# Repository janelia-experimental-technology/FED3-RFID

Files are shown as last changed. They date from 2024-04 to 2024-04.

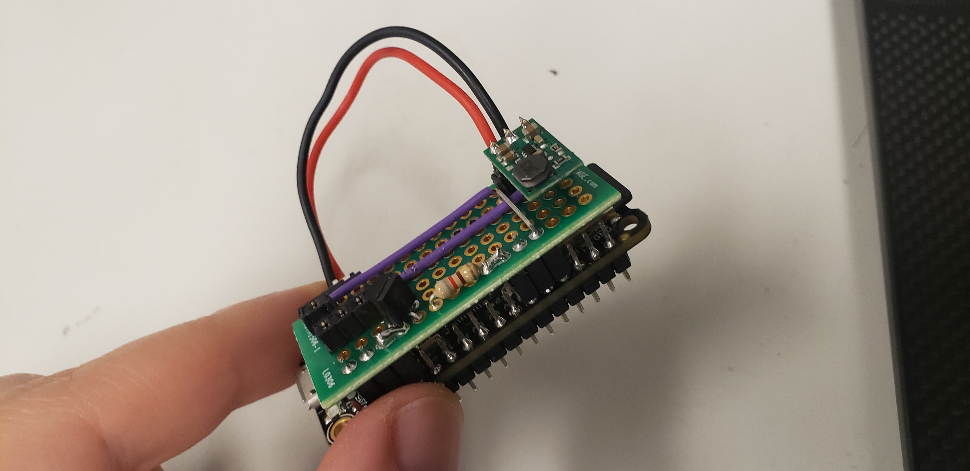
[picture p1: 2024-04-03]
ELECTRONICS/PHOTOS/20240327_181440.jpg

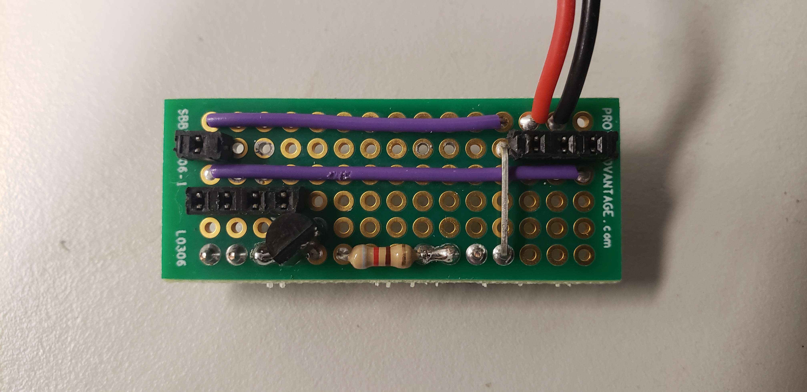
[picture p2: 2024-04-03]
ELECTRONICS/PHOTOS/20240327_181220.jpg

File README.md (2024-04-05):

This repo contains all the files necessary to integrate RFID with the Feeding Experimentation Device version 3 (FED3), originally developed by KravitzLabDevices.
This reader is compatible with FDX-B 134.2 kHz ISO 11784/85 transponders; the firmware was specifically developed to log both ID and temperature using the Biothem 13 Pit tags: https://www.biomark.com/product/biotherm13-pit-tag/

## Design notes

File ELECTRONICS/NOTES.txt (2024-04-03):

Refer to schematic, photos, and parts list for build.
In order to fit all electronics within the housing, short headers (male and female) should be used to limit height.
A 2mm JST connector can be used to connect the boost converter to the battery output from the Adafruit Feather M0.
A 2N4401 NPN BJT transistor was used, but a 2N2222 or similar would work just as well; be sure to adjust resistor value as needed.
It is advised to disconnect the battery from the FED3 board when not in use, ~18mA is drawn from the battery even when the FED3 is powered down.

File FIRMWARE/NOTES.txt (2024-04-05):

Upload "ClassicFED3_RFID.ino" in the examples folder to the Adafruit Feather M0 Adalogger.
The .cpp and .h files in "src" folder have been modified from the original FED3 code to allow for RFID integration.
Please note that RFID logging is currently only available on FEDModes 0-3.

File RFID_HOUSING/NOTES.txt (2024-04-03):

Files are for the acrylic antenna and tube mount which will attach to the FED3 housing - intended to be laser cut. 
Coil approximately 75 revolutions of 36 AWG magnet wire around tube to achieve an inductance of ~580uH.
Feed antenna wire through right nose-poke port to RFID reader board.
Make sure the antenna coil will be in close proximity to the animal's RFID tag.
Use three 2-56 screws and tap base plate to secure all acrylic sections together.
Press-fit two 6-32 nuts into base plate (make sure they are attracted to magnetic buttons on FED3).

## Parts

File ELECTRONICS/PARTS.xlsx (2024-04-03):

FED3 Documentation: | Ref Des | Link
Research |  | https://elifesciences.org/articles/66173
GitHub |  | https://github.com/KravitzLabDevices/FED3
Hardware:
Adafruit Feather Adalogger M0 | U3 | https://learn.adafruit.com/adafruit-feather-m0-adalogger/pinouts
9V Boost Converter | U2 | https://www.pololu.com/product/4944
FDX-B RFID Reader | U1 | https://www.amazon.com/LICHIFIT-134-2K-Module-ISO11784-Distance/dp/B0B8NXKPZB
Perf Board |  | https://www.digikey.com/en/products/detail/chip-quik-inc/SBBTH1506-1/5978222
Battery |  | https://www.pknergy.com/lithium-ion-battery-pack-3-7v-4400mah-2-product/?_gl=1*16tqxgu*_up*MQ..
820Ω resistor | R1
2N4401 BJT | Q1
24 AWG solid core wire
2mm JST connector (2 pos)
Female Headers |  | https://www.digikey.com/en/products/detail/3m/929870-01-10-RA/1239313?gad_source=1

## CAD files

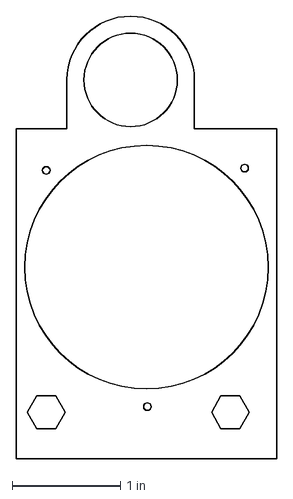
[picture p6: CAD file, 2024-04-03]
RFID_HOUSING/LASER CUT/BASE_PLATE.dxf
2.41 x 4.09 in

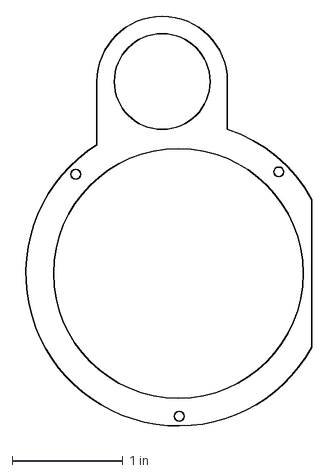
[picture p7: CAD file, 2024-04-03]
RFID_HOUSING/LASER CUT/TUBE_RING.dxf
2.67 x 3.76 in

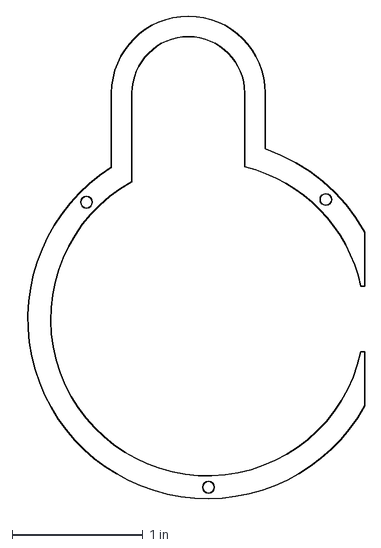
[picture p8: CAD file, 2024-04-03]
RFID_HOUSING/LASER CUT/ANTENNA_RING.dxf
2.67 x 3.76 in

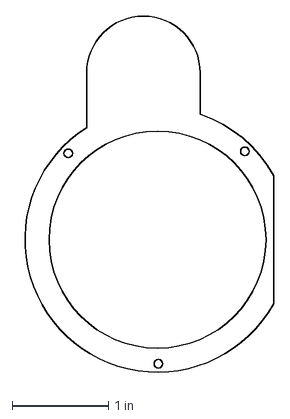
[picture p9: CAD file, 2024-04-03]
RFID_HOUSING/LASER CUT/END_CAP.dxf
2.67 x 3.76 in

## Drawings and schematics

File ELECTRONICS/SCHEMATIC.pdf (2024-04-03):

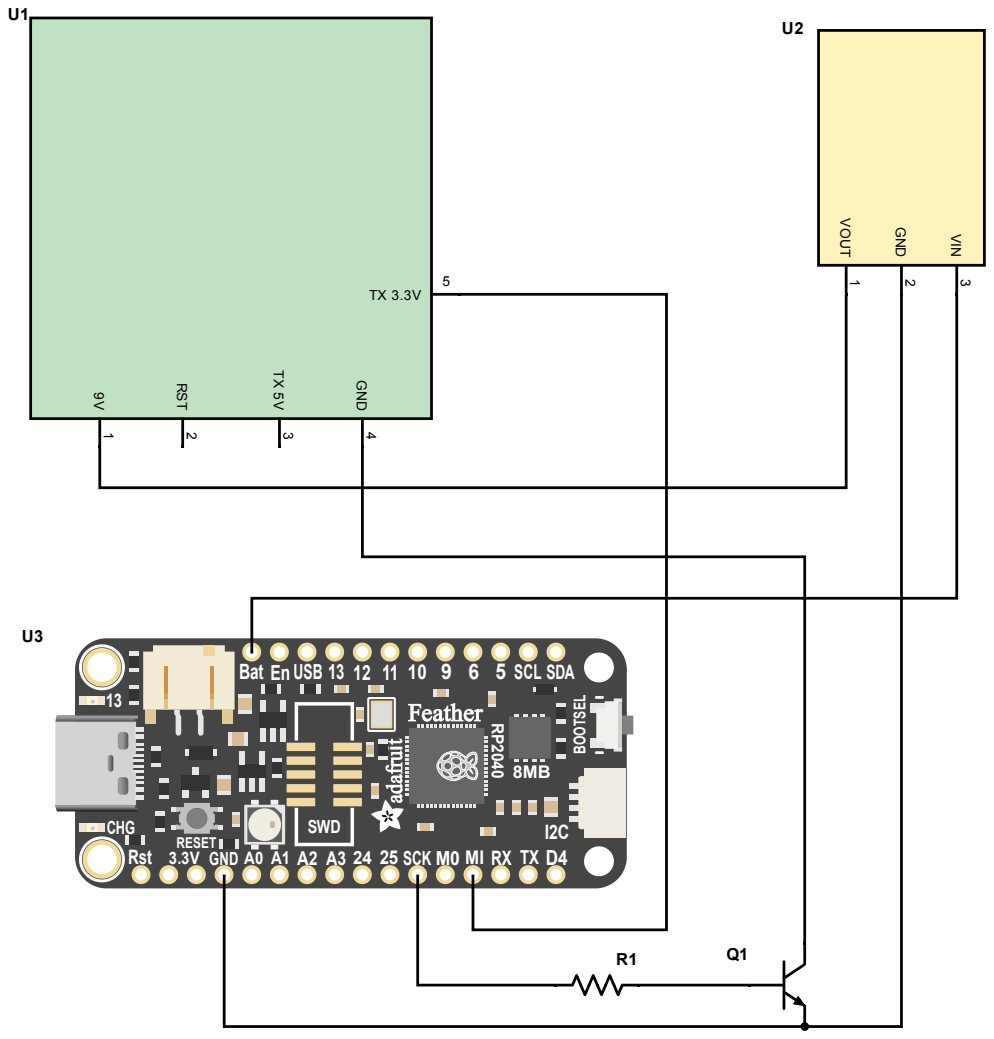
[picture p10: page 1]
RST; GND; V OUT; VIN; OTSEL; Feather; afruit; I2C RESET; CHG; SWD

Bat En USB 13 12 11 10 9

Rst 3.3V GND A0 A1 A2 A3 24 25 SCK M0 MI RX TX D4

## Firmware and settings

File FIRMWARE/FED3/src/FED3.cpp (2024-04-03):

/*
  RFID capabilities have been integrated into this program
  RFID reader: https://www.amazon.com/LICHIFIT-134-2K-Module-ISO11784-Distance/dp/B0B8NXKPZB
  Transponders: https://www.biomark.com/product/biotherm13-pit-tag/

  Daniel K. Smith
  smithd3@janelia.hhmi.org
  March 1, 2024

  /////////////////////////////////////////////////////////////////////////////////////////////////

  Feeding experimentation device 3 (FED3) library
  Code by Lex Kravitz, adapted to Arduino library format by Eric Lin
  alexxai@wustl.edu
  erclin@ucdavis.edu
  December 2020 

  The first FED device was developed by Nguyen at al and published in 2016:
  https://www.ncbi.nlm.nih.gov/pubmed/27060385

  FED3 includes hardware and code from:
  *** Adafruit, who made the hardware breakout boards and associated code we used in FED ***

  Cavemoa's excellent examples of datalogging with the Adalogger:
  https://github.com/cavemoa/Feather-M0-Adalogger

  Arduino Time library http://playground.arduino.cc/code/time
  Maintained by Paul Stoffregen https://github.com/PaulStoffregen/Time

  This project is released under the terms of the Creative Commons - Attribution - ShareAlike 3.0 license:
  human readable: https://creativecommons.org/licenses/by-sa/3.0/
  legal wording: https://creativecommons.org/licenses/by-sa/3.0/legalcode
  Copyright (c) 2019, 2020 Lex Kravitz
*/


/**************************************************************************************************************************************************
                                                                                                    Startup stuff
**************************************************************************************************************************************************/
#include "Arduino.h"
#include "FED3.h"

//  Start FED3 and RTC objects
FED3 *pointerToFED3;
RTC_PCF8523 rtc; 

//  Interrupt handlers
static void outsidePelletTriggerHandler(void) {
  pointerToFED3->pelletTrigger();
}

static void outsideLeftTriggerHandler(void) {
  pointerToFED3->leftTrigger();
}

static void outsideRightTriggerHandler(void) {
  pointerToFED3->rightTrigger();
}

/**************************************************************************************************************************************************
                                                                                                        Main loop
**************************************************************************************************************************************************/
void FED3::run() {
  //This should be called at least once per loop.  It updates the time, updates display, and controls sleep 
  if (digitalRead(PELLET_WELL) == HIGH) {  //check for pellet
    PelletAvailable = false;
  }
  DateTime now = rtc.now();
  currentHour = now.hour(); //useful for timed feeding sessions
  currentMinute = now.minute(); //useful for timed feeding sessions
  currentSecond = now.second(); //useful for timed feeding sessions
  unixtime = now.unixtime();
  ReadBatteryLevel();
  UpdateDisplay();
  goToSleep();
}

/**************************************************************************************************************************************************
                                                                                                Poke functions
**************************************************************************************************************************************************/
//log left poke
void FED3::logLeftPoke(){
  if (PelletAvailable == false){
    leftPokeTime = millis();
    LeftCount ++;
    leftInterval = 0.0;
    while (digitalRead (LEFT_POKE) == LOW) {}  //Hang here until poke is clear
    leftInterval = (millis()-leftPokeTime);
    UpdateDisplay();
    DisplayLeftInt();
    if (leftInterval < minPokeTime) {
      Event = "LeftShort";
    }
    else{
      Event = "Left";
    }
    logdata();
    Left = false;
  }
}

//log right poke
void FED3::logRightPoke(){
  if (PelletAvailable == false){
    rightPokeTime = millis();
    RightCount ++;
    rightInterval = 0.0;
    while (digitalRead (RIGHT_POKE) == LOW) {} //Hang here until poke is clear
    rightInterval = (millis()-rightPokeTime);
    UpdateDisplay();
    DisplayRightInt();
    if (rightInterval < minPokeTime) {
      Event = "RightShort";
    }
    else{
      Event = "Right";
    }
    logdata();
    Right = false; 
  }
}

void FED3::randomizeActivePoke(int max){
  //Store last active side and randomize
  byte lastActive = activePoke;
  activePoke = random (0, 2);

  //Increment consecutive active pokes, or reset consecutive to zero
  if (activePoke == lastActive) {
    consecutive ++;
  }
  else {
    consecutive = 0;
  }
  
  //if consecutive pokes are too many, swap pokes
  if (consecutive >= max){
    if (activePoke == 0) {
      activePoke = 1;
    }
    else if (activePoke == 1) {
      activePoke = 0;
    }
    consecutive = 0;
    }
}
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

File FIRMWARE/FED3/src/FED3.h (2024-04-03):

/*
RFID capabilities have been integrated into this program
RFID reader: https://www.amazon.com/LICHIFIT-134-2K-Module-ISO11784-Distance/dp/B0B8NXKPZB
Transponders: https://www.biomark.com/product/biotherm13-pit-tag/

Daniel K. Smith
smithd3@janelia.hhmi.org
March 1, 2024

/////////////////////////////////////////////////////////////////////////////////////////////////

Feeding experimentation device 3 (FED3) library 
Code by Lex Kravitz, adapted to Arduino library format by Eric Lin
alexxai@wustl.edu
May 2021

The original FED device was developed by Katrina Nguyen at al in 2016:
https://www.ncbi.nlm.nih.gov/pubmed/27060385

This device includes hardware and code from:
  *** Adafruit, who made the hardware breakout boards and associated code we used in FED ***

  Cavemoa's excellent examples of datalogging with the Adalogger:
  https://github.com/cavemoa/Feather-M0-Adalogger

  Arduino Time library http://playground.arduino.cc/code/time
  Maintained by Paul Stoffregen https://github.com/PaulStoffregen/Time

  This project is released under the terms of the Creative Commons - Attribution - ShareAlike 3.0 license:
  human readable: https://creativecommons.org/licenses/by-sa/3.0/
  legal wording: https://creativecommons.org/licenses/by-sa/3.0/legalcode
  Copyright (c) 2019, 2020 Lex Kravitz
*/

#define VER "1.16.3"

#ifndef FED3_H
#define FED3_H

//include these libraries
#include <Arduino.h>
#include <Adafruit_BusIO_Register.h>
#include <Adafruit_I2CDevice.h>
#include <Adafruit_I2CRegister.h>
#include <Adafruit_SPIDevice.h>
#include <Wire.h>
#include <SPI.h>
#include <Stepper.h>
#include <ArduinoLowPower.h>
#include "RTClib.h"
#include <SdFat.h>
#include <Adafruit_GFX.h>
#include <Adafruit_SharpMem.h>
#include <Fonts/FreeSans9pt7b.h>
#include <Fonts/Org_01.h>
#include <Adafruit_NeoPixel.h>
#include <Adafruit_AHTX0.h>

// Pin definitions
#define NEOPIXEL        A1
#define MOTOR_ENABLE    13
#define GREEN_LED       8
#define PELLET_WELL     1
#define LEFT_POKE       6
#define RIGHT_POKE      5            //DISABLE RIGHT NOSE-POKE (OTHERWISE PIN 5)
#define BUZZER          0
#define VBATPIN         A7
#define cardSelect      4
#define BNC_OUT         A0
#define SHARP_SCK       12
#define SHARP_MOSI      11
#define SHARP_SS        10
#define RFID_RST        24
         

#define BLACK 0
#define WHITE 1
#define STEPS 2038

extern bool Left;

class FED3 {
    // Members
    public:
        FED3(String sketch);
        String sketch = "undef";
        String sessiontype = "undef";

        void classInterruptHandler(void);
        void begin();
        void run();
        
        // SD logging
        SdFat SD;
        File logfile;       // Create file object
        File ratiofile;     // Create another file object
        File configfile;    // Create another file object
        File startfile;     // Create another file object
        File stopfile;      // Create another file object
        char filename[21];  // Array for file name data logged to named in setup
        void logdata();
        void CreateFile();
        void CreateDataFile ();
        void writeHeader();
        void writeConfigFile();
        void writeFEDmode();
        void error(uint8_t errno);
        void getFilename(char *filename);
        bool suppressSDerrors = false;  //set to true to suppress SD card errors at startup 

        // Battery
        float measuredvbat = 1.0;
        void ReadBatteryLevel();

        // Neopixel
        void pixelsOn(int R, int G, int B, int W);
        void pixelsOff();
        void Blink(byte PIN, byte DELAY_MS, byte loops);
        void colorWipe(uint32_t c, uint8_t wait);
        void leftPixel(int R, int G, int B, int W);
        void rightPixel(int R, int G, int B, int W);
        void leftPokePixel(int R, int G, int B, int W);
        void rightPokePixel(int R, int G, int B, int W);
        
        // Display functions
        void UpdateDisplay();
        void DisplaySDError();
        void DisplayJamClear();
        void DisplayRetrievalInt();
        void DisplayLeftInt();
        void DisplayRightInt();
        void DisplayBattery();
        void DisplayDateTime();
        void DisplayIndicators();
        void DisplayTimedFeeding();
        void DisplayNoProgram();
        void DisplayMinPoke();
        void DisplayMouse();

        // Startup menu function
        void ClassicMenu();
        void StartScreen();
        void FED3MenuScreen();
        void SetClock();
        
        //BNC input/output
		void ReadBNC(bool blinkGreen);
        bool BNCinput = false;
        
        // Motor
        void ReleaseMotor();
        int numMotorTurns = 0;

        // Set FED
        void SelectMode();
        void SetDeviceNumber();

        // Stimuli
        void ConditionedStimulus(int duration = 200);
        void Click();
        void Noise(int duration = 200);
        void BNC(int DELAY_MS, int loops);
        void pulseGenerator(int pulse_width, int frequency, int repetitions);

        void Tone(int freq, int duration);
        void stopTone();
        
        // Pelet and poke functions
        void CheckRatio();
        void logLeftPoke();
        void logRightPoke();
        void Feed(int pulse = 0, bool pixelsoff = true);
        bool dispenseTimer_ms(int ms);
        void pelletTrigger();
        void leftTrigger();
        void rightTrigger();
        void goToSleep();
        void Timeout(int timeout);
        int minPokeTime = 0;
        void randomizeActivePoke(int max);
        int consecutive = 0;

        // RFID functions
        void rfidRun();
        void rfidInit();
        byte incomingByte;
        byte buffer[30];
        uint8_t index;
        boolean started = false;
        byte XOR;
        byte inverted;
        uint32_t rfidTag = 0;
        float rfidTemp = 0.0;
	    uint32_t temp = 0;
        bool checksum = false;
        bool invChecksum = false;
        void logRFIDData();
        
        
        //jam movements
		bool RotateDisk(int steps);
        bool ClearJam();
        bool VibrateJam();
        bool MinorJam();

        //timed feeding variables
        int timedStart; //hour to start the timed Feeding session, out of 24 hour clock
        int timedEnd; //hour to start the timed Feeding session, out of 24 hour clock
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

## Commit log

2024-04-03 Files uploaded
    [ANTENNA_RING.dxf, BASE_PLATE.dxf, END_CAP.dxf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]
2024-04-05 renamed folders
    [ANTENNA_RING.dxf, BASE_PLATE.dxf, END_CAP.dxf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]
